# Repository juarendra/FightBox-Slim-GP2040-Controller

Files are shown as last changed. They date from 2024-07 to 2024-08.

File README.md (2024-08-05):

# FightBox-Slim-GP2040-Controller
## Table of Content

* [Product Specsification](#product-specsification)
* [Technical Spesification](#technical-spesification)
* [Priview Hardware](#priview-hardware)
* [Documentation](#documentation)
  * [Pinout Diagram](#pinout-diagram)
  * [Dimension](#dimension)
  * [BOM](#bom)
  * [Schematic](#schematic0)
  * [Example Program](#examples-program)
* [FAQ](#FAQ)

## Priview Hardware
<p align="center">
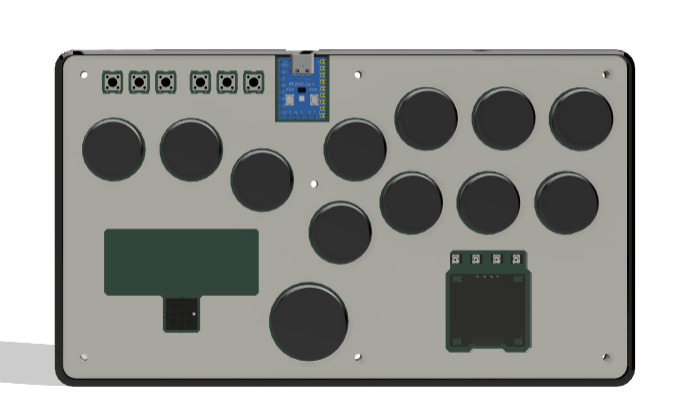
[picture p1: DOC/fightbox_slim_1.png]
  
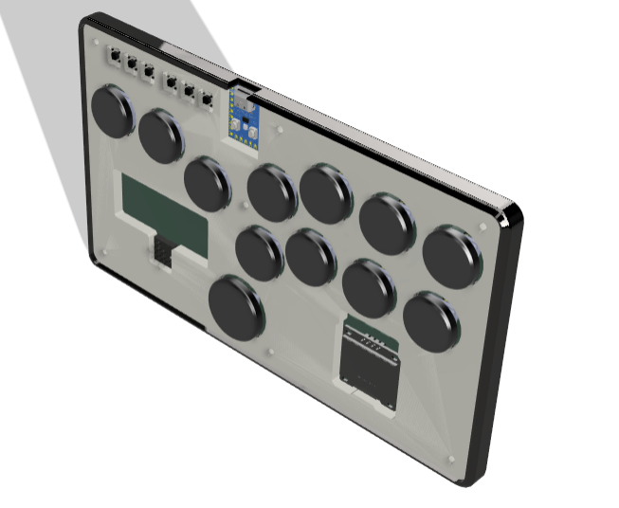
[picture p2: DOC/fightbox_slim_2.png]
  
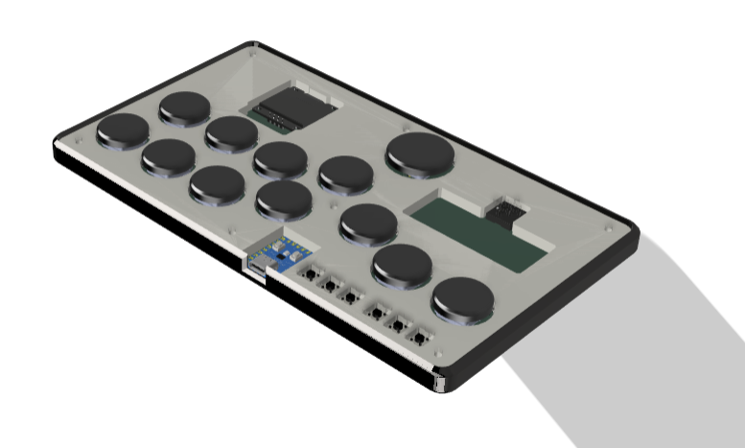
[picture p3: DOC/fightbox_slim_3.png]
  
  
</p>

## Documentation
### Pinout Diagram
<p align="center">
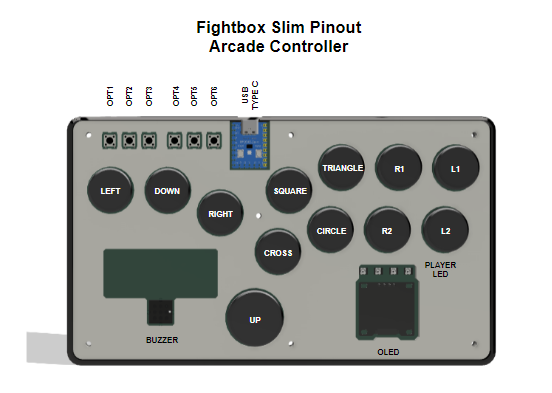
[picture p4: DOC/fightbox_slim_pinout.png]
  
</p>

### Dimension
* [Dimension Board with Component](https://github.com/juarendra/FightBox-Slim-GP2040-Controller/blob/main/HARDWARE/DIMENSION%20ACCES%20FIGHTBOX%20SLIM.pdf)
### BOM
* [BOM Board](https://github.com/juarendra/FightBox-Slim-GP2040-Controller/blob/main/DOC/BOM/FightBox_BOM.xlsx)
### Schematic
* [Schematic](https://github.com/juarendra/FightBox-Slim-GP2040-Controller/blob/main/HARDWARE/fightbox_slim_schematic.pdf)
### Pinout Diagram
* [Pinout Diagram](https://github.com/juarendra/FightBox-Slim-GP2040-Controller/blob/main/HARDWARE/Fightbox_slim_pinout.pdf)

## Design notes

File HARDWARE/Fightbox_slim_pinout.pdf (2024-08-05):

# Fightbox Slim Pinout Arcade Controller

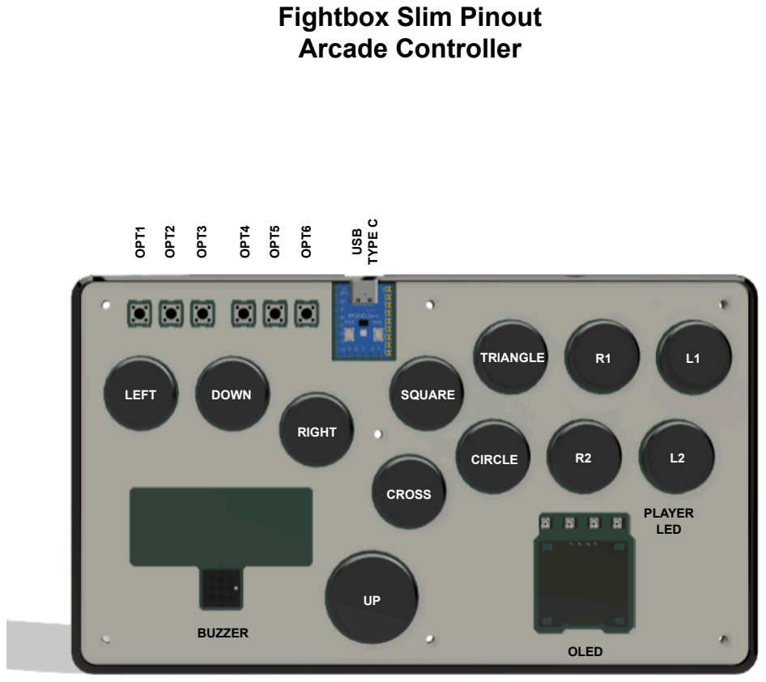
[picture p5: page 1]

LEFT | DOWN

RIGHT

CROSS

SQUARE

CIRCLE

TRIANGLE | R1
R2 | L2

L1

UP

OPT1

OPT2

OPT3

OPT4

OPT5
OPT6
USB

TYPE C

BUZZER
OLED

PLAYER
LED

# Fightbox Slim Pinout Arcade Controller

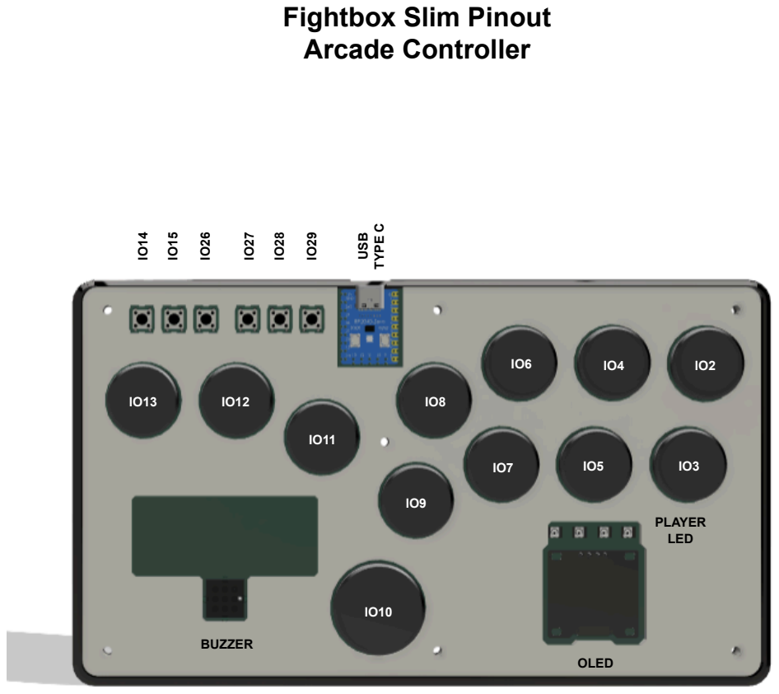
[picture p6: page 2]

IO13 | IO12

IO11

IO9

IO8

IO7

IO6 | IO4
IO5 | IO3 IO2

IO10

IO14

IO15
IO26

IO27

IO28
IO29
USB

TYPE C

BUZZER
OLED

PLAYER
LED

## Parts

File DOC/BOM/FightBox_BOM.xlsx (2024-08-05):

No | Ref | Qnty | Value | Cmp name | Footprint | Description | Tokopedia Link | Note
1 | A1 | 1 | RP2040-Zero | RP2040-Zero | RP2040-Zero:RP2040-Zero |  | https://www.tokopedia.com/hobielektronika/raspberry-pi-pico-rp2040-zero-mikrocontroller-dual-core-cortex-m0 | -
2 | Brd1 | 1 | SSD1306 | SSD1306 | oled:128x64OLED | SSD1306 OLED | https://tokopedia.link/G6XMfRS3NLb | -
3 | BZ1 | 1 | Buzzer | Buzzer | Buzzer_Beeper:Buzzer_Murata_PKLCS1212E | Buzzer, polarized | https://tokopedia.link/6FK5Z8Z3NLb | -
7 | L1, L2, L3, L4, L5, L6, L7, L8, L9, L10, L11, L12, L13, L14, L15, L16, L17, L18, L19, L20, L21, L22, L23, L24, L25, L26, L27, L28 | 28 | kbd_SK6812MINI | kbd_SK6812MINI | kbd:SK6812MINI_rev |  | https://tokopedia.link/y0GYifh4NLb | -
8 | SW1, SW2, SW3, SW4, SW5, SW6 | 6 | SW_Push | SW_Push | Button_Switch_THT:SW_PUSH_6mm_H5mm | Push button switch, generic, two pins | https://tokopedia.link/rqC0fJt4NLb | -
9 | SW7, SW8, SW9, SW10, SW11, SW12, SW13, SW14, SW15, SW16, SW17, SW18 | 12 | SW_Push | SW_Push | keyswitch:Kailh_socket_PG1350 | Push button switch, generic, two pins | https://tokopedia.link/b9QdQEr4NLb | -
10 | SW19, SW20, SW21, SW22, SW23, SW24, SW25, SW26, SW27, SW28, SW29, SW30 | 12 | SW_PUSH | SW_PUSH | keyswitch:Kailh_socket_MX |  | https://tokopedia.link/jJEvHtk4NLb | -

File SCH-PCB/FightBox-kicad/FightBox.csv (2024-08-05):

Source: | C:\Users\jrjua\Documents\Pribadi\Github\FightBox-Slim-GP2040-Controller\SCH-PCB\FightBox-kicad\FightBox.kicad_sch
Date: | 5/8/2024 11:39:31 am
Tool: | Eeschema 7.0.1
Generator: | C:\Program Files\KiCad\7.0\bin\scripting\plugins/bom_csv_grouped_by_value_with_fp.py
Component Count: | 78
Ref | Qnty | Value | Cmp name | Footprint | Description | Vendor | DNP
A1 | 1 | RP2040-Zero | RP2040-Zero | RP2040-Zero:RP2040-Zero
Brd1 | 1 | SSD1306 | SSD1306 | oled:128x64OLED | SSD1306 OLED
BZ1 | 1 | Buzzer | Buzzer | Buzzer_Beeper:Buzzer_Murata_PKLCS1212E | Buzzer, polarized
H1, H2, H3, H4, H5, H6, H7 | 7 | MountingHole | MountingHole | MountingHole:MountingHole_6.4mm_M6 | Mounting Hole without connection
J1, J2, J3, J4, J5 | 5 | i2c_pin-Lily58-cache | i2c_pin-Lily58-cache | solfe:1pin_conn
JP1, JP2, JP3 | 3 | Jumper_3_Open | Jumper_3_Open | Jumper:SolderJumper-3_P1.3mm_Open_RoundedPad1.0x1.5mm | Jumper, 3-pole, both open
JP4, JP5 | 2 | Jumper_2_Open | Jumper_2_Open | Jumper:SolderJumper-2_P1.3mm_Open_RoundedPad1.0x1.5mm | Jumper, 2-pole, open
L1, L2, L3, L4, L5, L6, L7, L8, L9, L10, L11, L12, L13, L14, L15, L16, L17, L18, L19, L20, L21, L22, L23, L24, L25, L26, L27, L28 | 28 | kbd_SK6812MINI | kbd_SK6812MINI | kbd:SK6812MINI_rev
SW1, SW2, SW3, SW4, SW5, SW6 | 6 | SW_Push | SW_Push | Button_Switch_THT:SW_PUSH_6mm_H5mm | Push button switch, generic, two pins
SW7, SW8, SW9, SW10, SW11, SW12, SW13, SW14, SW15, SW16, SW17, SW18 | 12 | SW_Push | SW_Push | keyswitch:Kailh_socket_PG1350 | Push button switch, generic, two pins
SW19, SW20, SW21, SW22, SW23, SW24, SW25, SW26, SW27, SW28, SW29, SW30 | 12 | SW_PUSH | SW_PUSH | keyswitch:Kailh_socket_MX

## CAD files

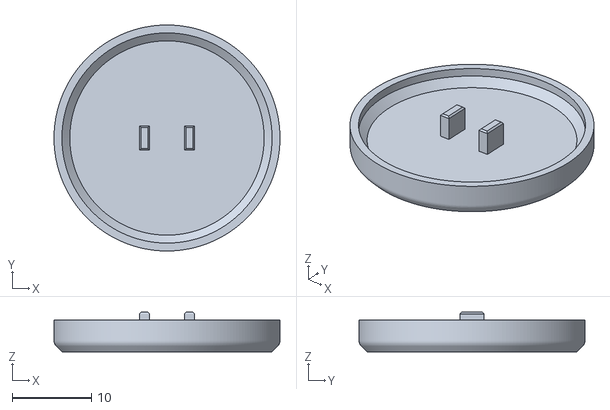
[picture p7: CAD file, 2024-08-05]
HARDWARE/3d Case/ButtoncapBig.stl
28.5 x 28.5 x 5.00

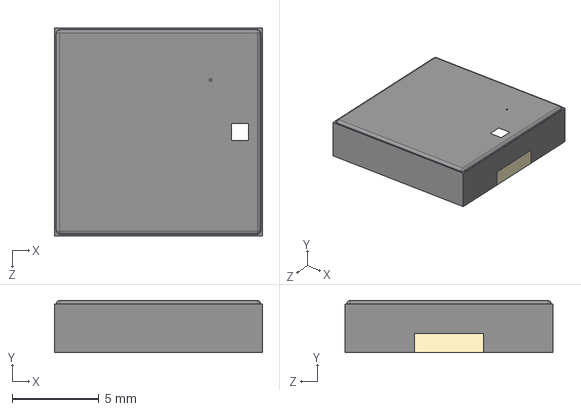
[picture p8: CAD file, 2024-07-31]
SCH-PCB/FightBox-kicad/3d/PKLCS1212E2400-R1.stp
12.0 x 3.00 x 12.0 mm

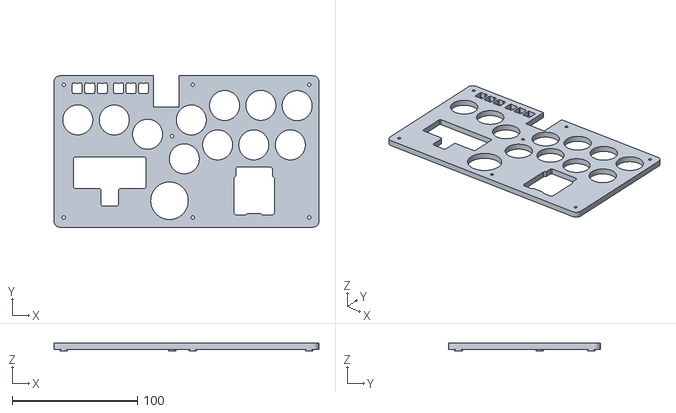
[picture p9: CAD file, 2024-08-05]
HARDWARE/3d Case/fightingbox_slim_MIDDLE_CASE.stl
211.6 x 121.0 x 6.20

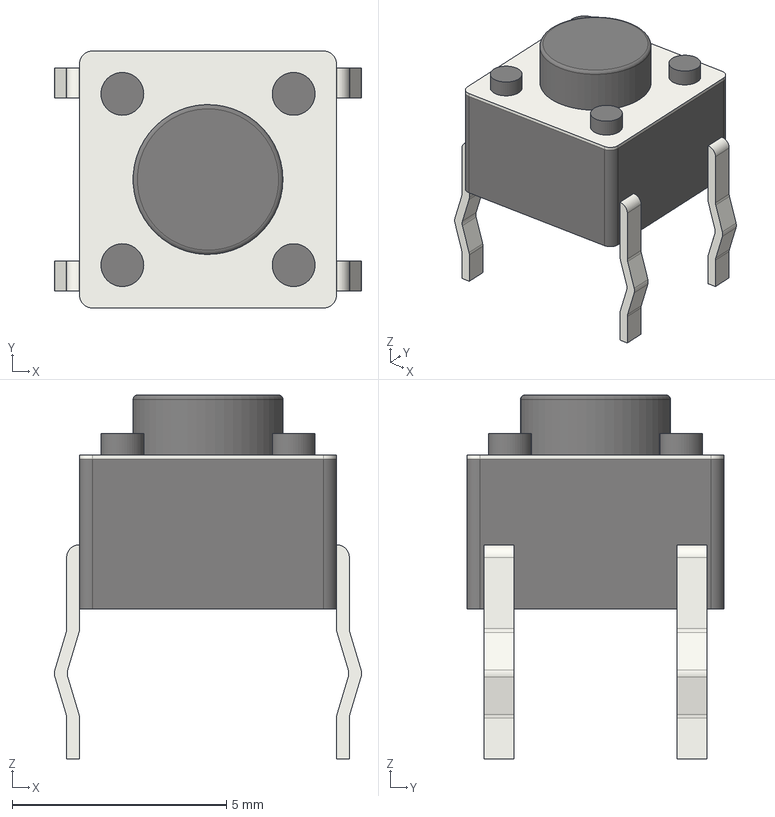
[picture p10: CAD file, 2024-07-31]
SCH-PCB/FightBox-kicad/3d/SW_PUSH_6mm_H5mm.step
7.17 x 6.00 x 8.50 mm

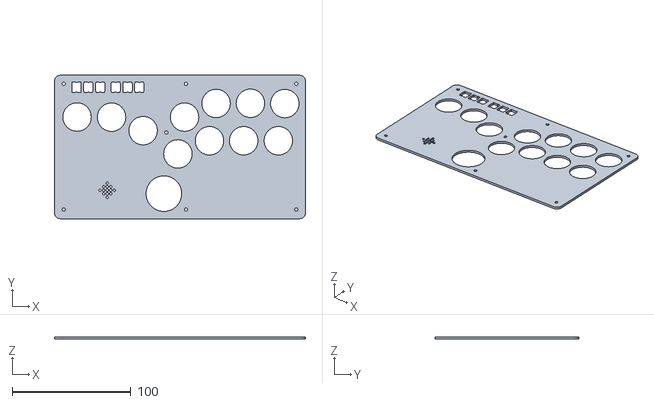
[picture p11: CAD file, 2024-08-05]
HARDWARE/3d Case/fightingbox_slim_TOP_CASE.stl
211.6 x 121.0 x 2.00

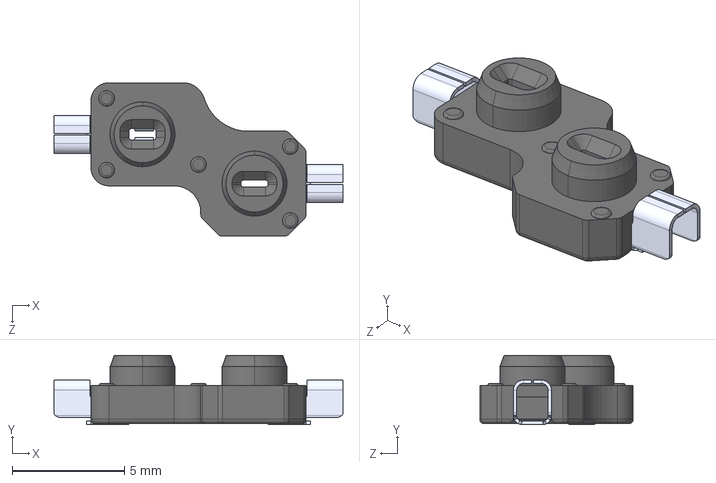
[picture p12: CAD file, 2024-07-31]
SCH-PCB/FightBox-kicad/3d/PG1350-socket.STEP
12.9 x 3.09 x 6.85 mm
pin x 2
socket

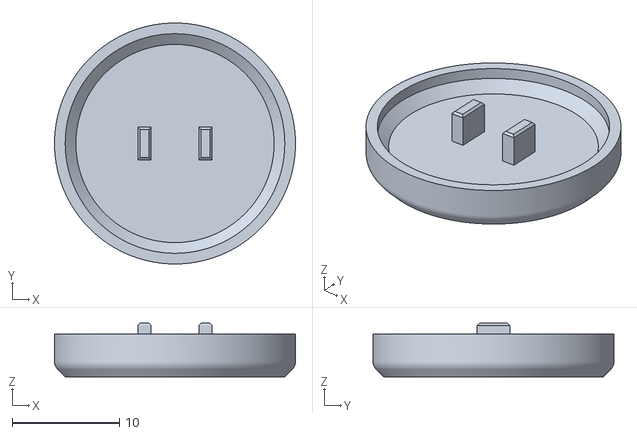
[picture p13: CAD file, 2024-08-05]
HARDWARE/3d Case/Buttoncap.stl
22.5 x 22.5 x 5.00

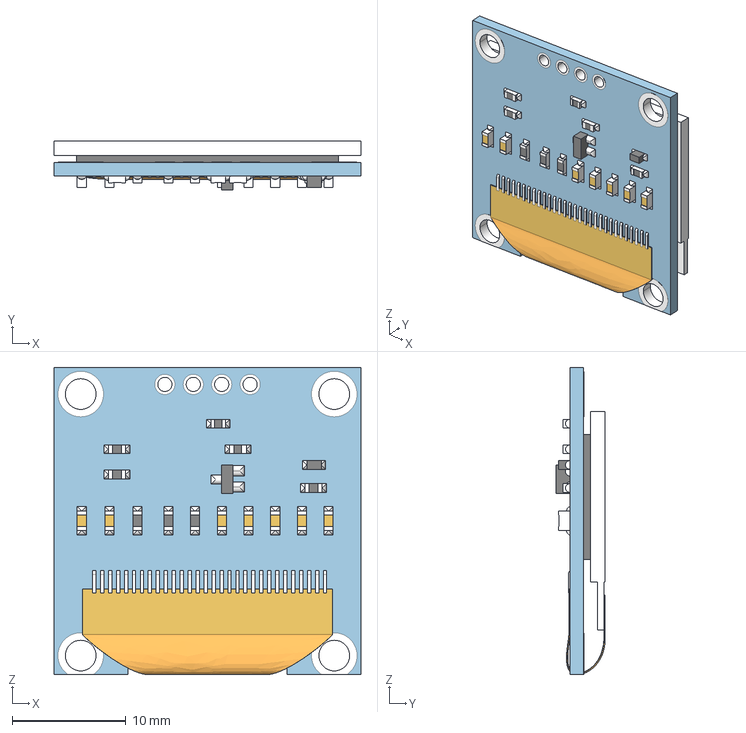
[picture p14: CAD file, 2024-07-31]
SCH-PCB/FightBox-kicad/3d/oled_096_gm009605.stp
27.0 x 4.35 x 27.0 mm

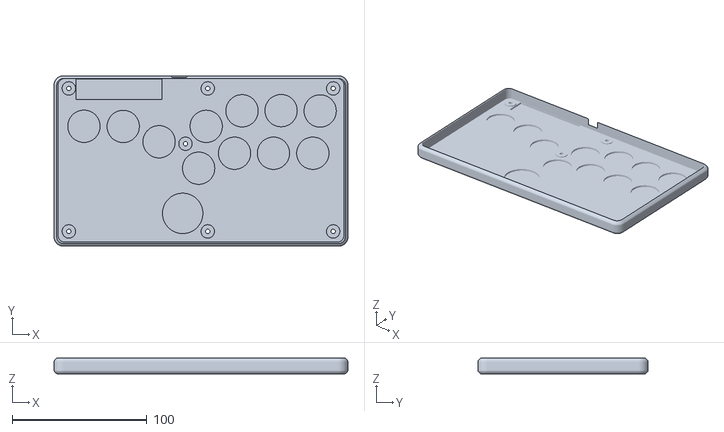
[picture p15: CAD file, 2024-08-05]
HARDWARE/3d Case/fightingbox_slim_BOTTOM_CASE.stl
218.0 x 126.4 x 11.8

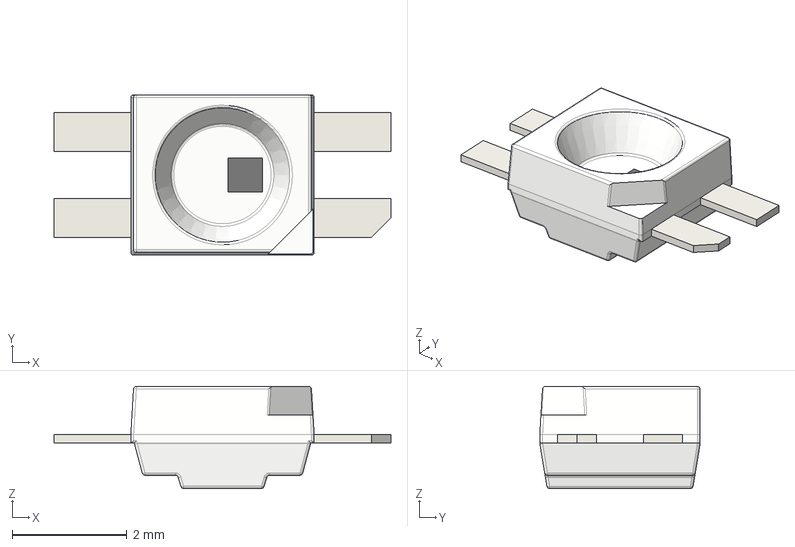
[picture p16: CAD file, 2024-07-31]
SCH-PCB/FightBox-kicad/3d/LED_SK6812MINI-E.step
5.88 x 2.80 x 1.78 mm

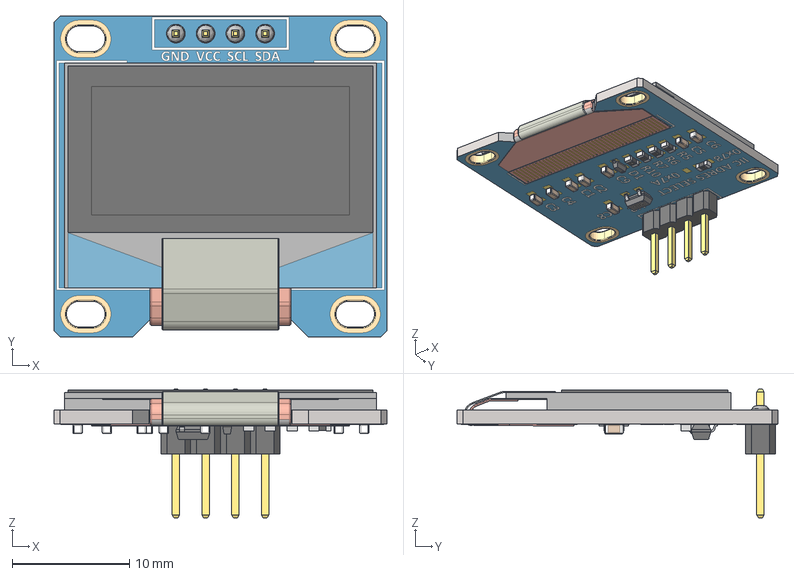
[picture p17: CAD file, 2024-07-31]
SCH-PCB/FightBox-kicad/3d/Pantalla OLED 0.96'' 128x64.stp
28.4 x 27.4 x 11.0 mm
SOT-23_TOR
RES_CR16_MTK_1 x 4
RES_CR16_MTK
SOD323F_DIO

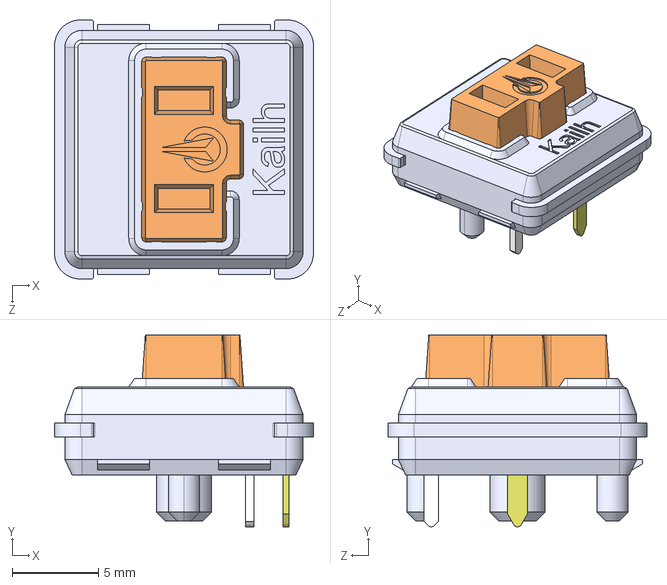
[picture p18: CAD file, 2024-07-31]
SCH-PCB/FightBox-kicad/3d/Kailh LP Choc Burnt Orange.IGS
15.0 x 11.1 x 15.0 mm

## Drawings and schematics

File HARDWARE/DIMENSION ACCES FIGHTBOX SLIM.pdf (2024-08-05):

121 | Ø2.8 ⁹.74 11.47 | Ø3.5

11.8

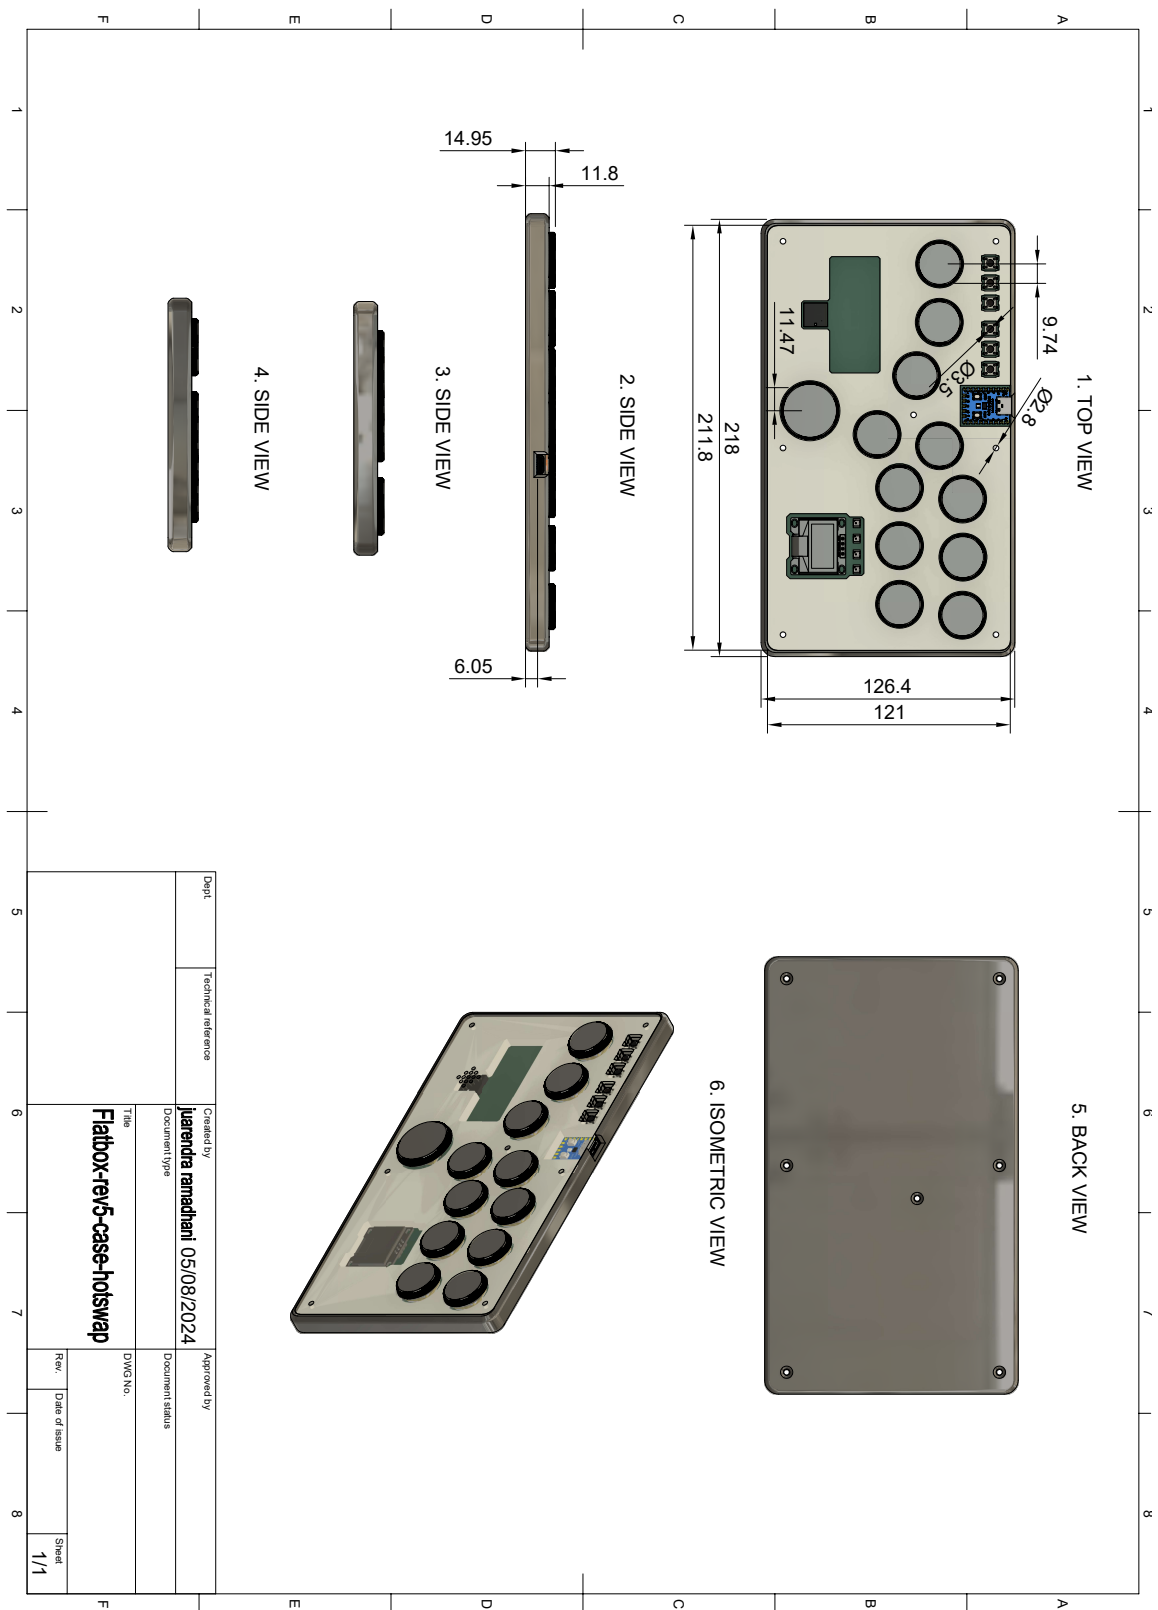
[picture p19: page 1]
126.4 ²¹⁸ ²¹¹.8; 6.05 ⁴. SIDE VIEW; 3. SIDE VIEW; 2. SIDE VIEW; 1. TOP VIEW 6. ISOMETRIC VIEW; 5. BACK VIEW

1 A 2 3 4 5 6 7 8 1 2 3 4 5 6 7 8 FEDCB FEDCBA Dept. Technical reference Created by Approved by Title DWG No. Document type Document status Rev. Date of issue Sheet 05/08/2024 1/1

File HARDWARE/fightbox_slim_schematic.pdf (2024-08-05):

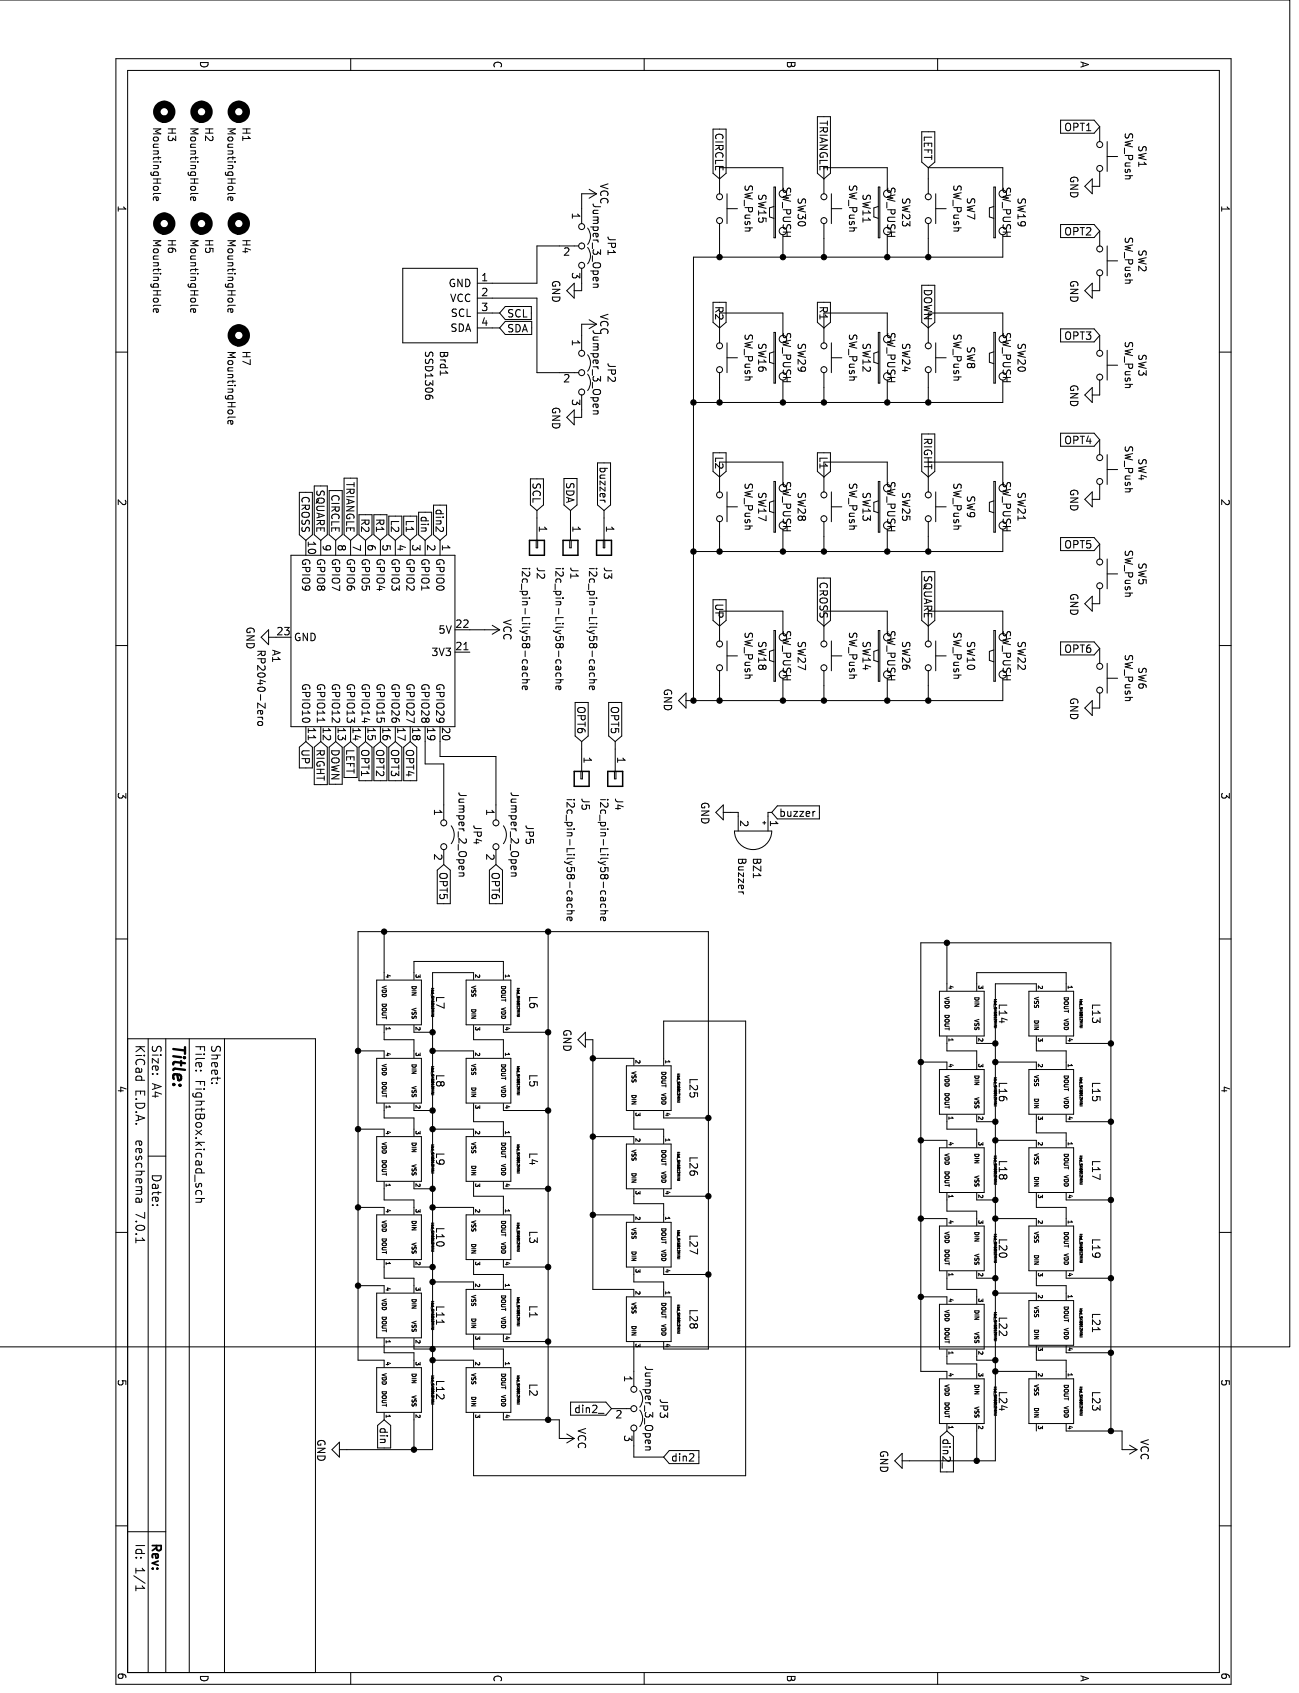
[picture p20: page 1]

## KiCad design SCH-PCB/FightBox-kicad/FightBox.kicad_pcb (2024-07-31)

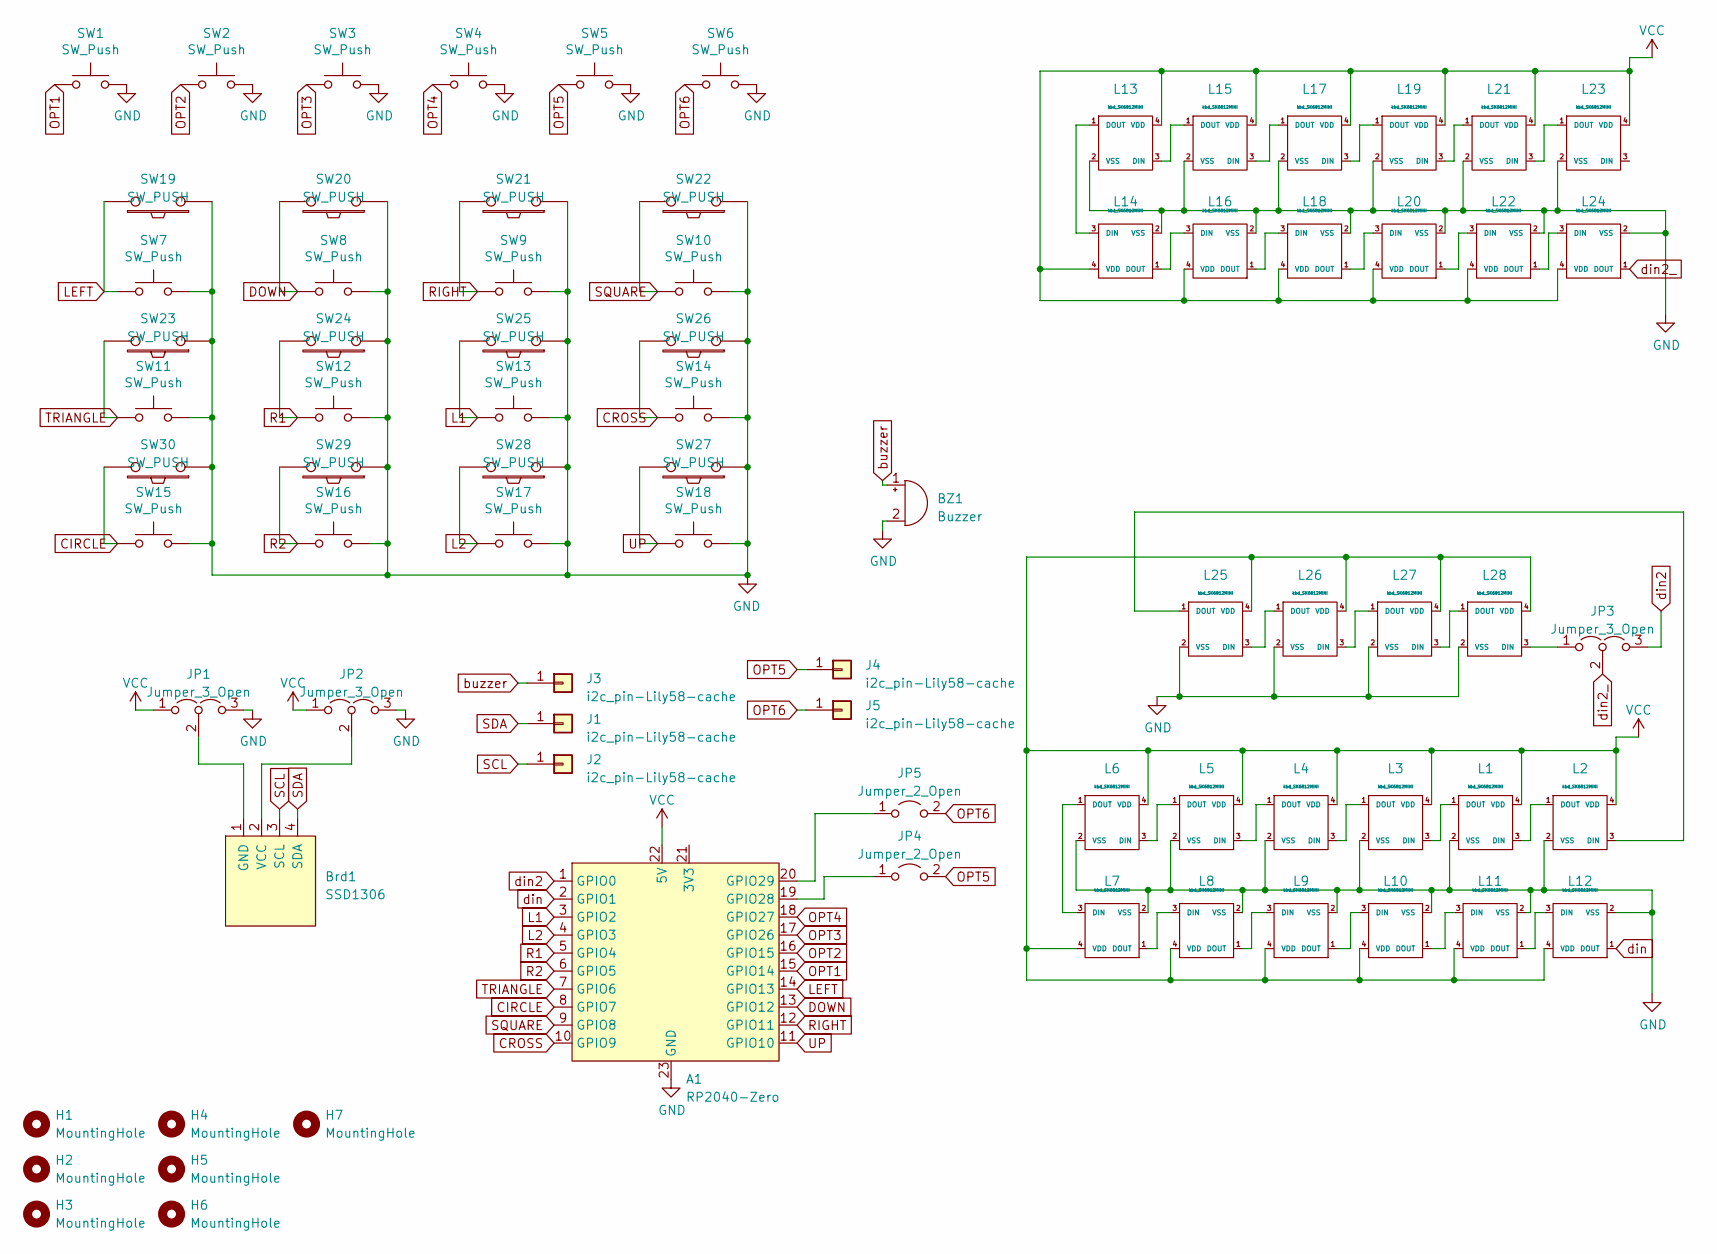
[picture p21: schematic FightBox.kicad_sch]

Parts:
A1: RP2040-Zero
BZ1: Buzzer; Buzzer_Murata_PKLCS1212E
Brd1: SSD1306; 128x64OLED
H1, H2, H3, H4, H5, H6, H7: MountingHole; MountingHole_6.4mm_M6
J1, J2, J3, J4, J5: i2c_pin-Lily58-cache; 1pin_conn
JP1, JP2, JP3: Jumper_3_Open; SolderJumper-3_P1.3mm_Open_RoundedPad1.0x1.5mm
JP4, JP5: Jumper_2_Open; SolderJumper-2_P1.3mm_Open_RoundedPad1.0x1.5mm
L1, L2, L3, L4, L5, L6, L7, L8, L9, L10, L11, L12, L13, L14, L15, L16, L17, L18, L19, L20, L21, L22, L23, L24, L25, L26, L27, L28: kbd_SK6812MINI; SK6812MINI_rev
SW1, SW2, SW3, SW4, SW5, SW6: SW_Push; SW_PUSH_6mm_H5mm
SW7, SW8, SW9, SW10, SW11, SW12, SW13, SW14, SW15, SW16, SW17, SW18: SW_Push; Kailh_socket_PG1350
SW19, SW20, SW21, SW22, SW23, SW24, SW25, SW26, SW27, SW28, SW29, SW30: SW_PUSH; Kailh_socket_MX

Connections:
CIRCLE: A1.8 (GPIO7), SW15.1, SW30.2
CROSS: A1.10 (GPIO9), SW14.1, SW26.2
DOWN: A1.13 (GPIO12), SW8.1, SW20.2
GND: A1.23 (GND), BZ1.2 (+), JP1.3 (B), JP2.3 (B), L1.2 (VSS), L2.2 (VSS), L3.2 (VSS), L4.2 (VSS), L5.2 (VSS), L6.2 (VSS), L7.2 (VSS), L8.2 (VSS), L9.2 (VSS), L10.2 (VSS), L11.2 (VSS), L12.2 (VSS), L13.2 (VSS), L14.2 (VSS), L15.2 (VSS), L16.2 (VSS), L17.2 (VSS), L18.2 (VSS), L19.2 (VSS), L20.2 (VSS), L21.2 (VSS), L22.2 (VSS), L23.2 (VSS), L24.2 (VSS), L25.2 (VSS), L26.2 (VSS), L27.2 (VSS), L28.2 (VSS), SW1.2, SW2.2, SW3.2, SW4.2, SW5.2, SW6.2, SW7.2, SW8.2, SW9.2, SW10.2, SW11.2, SW12.2, SW13.2, SW14.2, SW15.2, SW16.2, SW17.2, SW18.2, SW19.1, SW20.1, SW21.1, SW22.1, SW23.1, SW24.1, SW25.1, SW26.1, SW27.1, SW28.1, SW29.1, SW30.1
L1: A1.3 (GPIO2), SW13.1, SW25.2
L2: A1.4 (GPIO3), SW17.1, SW28.2
LEFT: A1.14 (GPIO13), SW7.1, SW19.2
unnamed: A1.19 (GPIO28), JP4.1 (A)
unnamed: A1.20 (GPIO29), JP5.1 (A)
unnamed: Brd1.1 (GND), JP1.2 (C)
unnamed: Brd1.2 (VCC), JP2.2 (C)
unnamed: JP3.1 (A), L28.3 (DIN)
unnamed: L1.3 (DIN), L2.1 (DOUT)
unnamed: L1.1 (DOUT), L3.3 (DIN)
unnamed: L2.3 (DIN), L25.1 (DOUT)
unnamed: L3.1 (DOUT), L4.3 (DIN)
unnamed: L4.1 (DOUT), L5.3 (DIN)
unnamed: L5.1 (DOUT), L6.3 (DIN)
unnamed: L6.1 (DOUT), L7.3 (DIN)
unnamed: L7.1 (DOUT), L8.3 (DIN)
unnamed: L8.1 (DOUT), L9.3 (DIN)
unnamed: L9.1 (DOUT), L10.3 (DIN)
unnamed: L10.1 (DOUT), L11.3 (DIN)
unnamed: L11.1 (DOUT), L12.3 (DIN)
unnamed: L13.3 (DIN), L15.1 (DOUT)
unnamed: L13.1 (DOUT), L14.3 (DIN)
unnamed: L14.1 (DOUT), L16.3 (DIN)
unnamed: L15.3 (DIN), L17.1 (DOUT)
unnamed: L16.1 (DOUT), L18.3 (DIN)
unnamed: L17.3 (DIN), L19.1 (DOUT)
unnamed: L18.1 (DOUT), L20.3 (DIN)
unnamed: L19.3 (DIN), L21.1 (DOUT)
unnamed: L20.1 (DOUT), L22.3 (DIN)
unnamed: L21.3 (DIN), L23.1 (DOUT)
unnamed: L22.1 (DOUT), L24.3 (DIN)
unnamed: L25.3 (DIN), L26.1 (DOUT)
unnamed: L26.3 (DIN), L27.1 (DOUT)
unnamed: L27.3 (DIN), L28.1 (DOUT)
OPT1: A1.15 (GPIO14), SW1.1
OPT2: A1.16 (GPIO15), SW2.1
OPT3: A1.17 (GPIO26), SW3.1
OPT4: A1.18 (GPIO27), SW4.1
OPT5: J4.1, JP4.2 (B), SW5.1
OPT6: J5.1, JP5.2 (B), SW6.1
R1: A1.5 (GPIO4), SW12.1, SW24.2
R2: A1.6 (GPIO5), SW16.1, SW29.2
RIGHT: A1.12 (GPIO11), SW9.1, SW21.2
SCL: Brd1.3 (SCL), J2.1
SDA: Brd1.4 (SDA), J1.1
SQUARE: A1.9 (GPIO8), SW10.1, SW22.2
TRIANGLE: A1.7 (GPIO6), SW11.1, SW23.2
UP: A1.11 (GPIO10), SW18.1, SW27.2
VCC: A1.22 (5V), JP1.1 (A), JP2.1 (A), L1.4 (VDD), L2.4 (VDD), L3.4 (VDD), L4.4 (VDD), L5.4 (VDD), L6.4 (VDD), L7.4 (VDD), L8.4 (VDD), L9.4 (VDD), L10.4 (VDD), L11.4 (VDD), L12.4 (VDD), L13.4 (VDD), L14.4 (VDD), L15.4 (VDD), L16.4 (VDD), L17.4 (VDD), L18.4 (VDD), L19.4 (VDD), L20.4 (VDD), L21.4 (VDD), L22.4 (VDD), L23.4 (VDD), L24.4 (VDD), L25.4 (VDD), L26.4 (VDD), L27.4 (VDD), L28.4 (VDD)
buzzer: BZ1.1 (-), J3.1
din: A1.2 (GPIO1), L12.1 (DOUT)
din2: A1.1 (GPIO0), JP3.3 (B)
din2_: JP3.2 (C), L24.1 (DOUT)

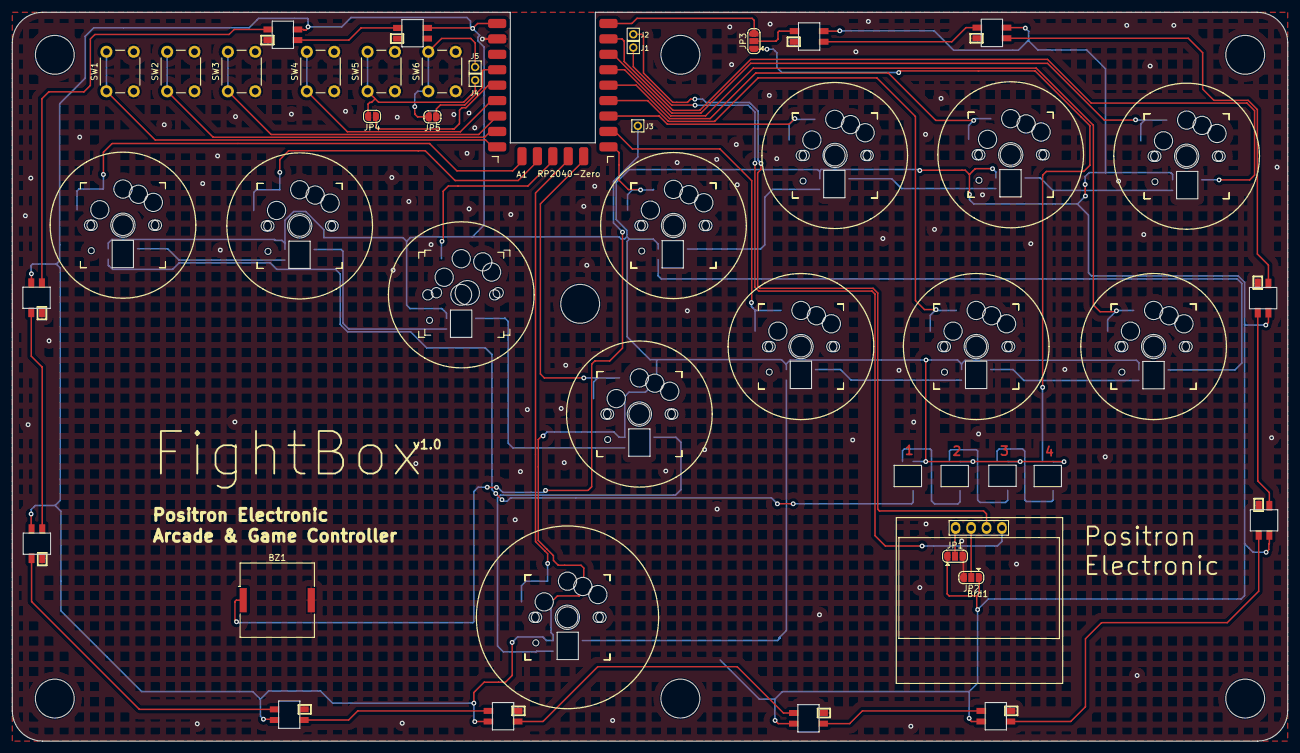
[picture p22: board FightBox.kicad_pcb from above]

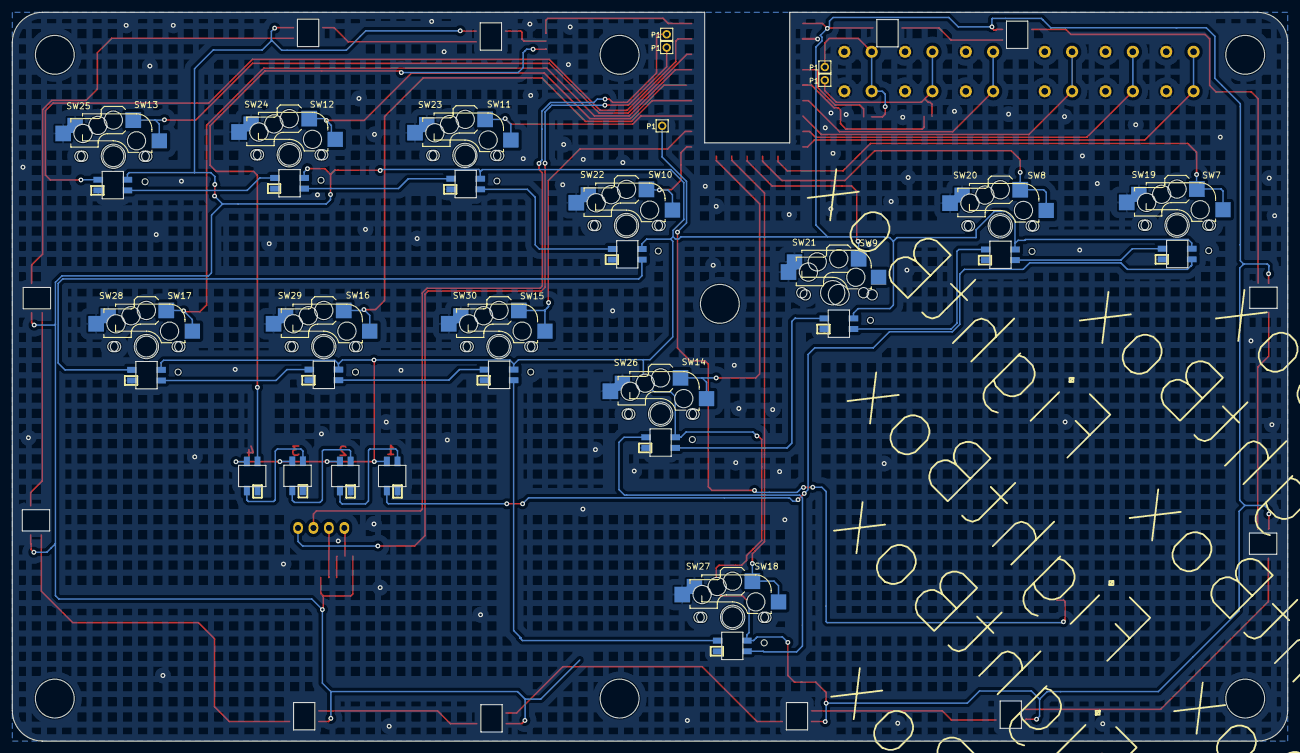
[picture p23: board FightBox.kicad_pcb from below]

Board: 2 copper layers, 210.0 x 120.0 mm, 78 parts (12 on the bottom side), 57 nets.

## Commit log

2024-08-05 FEAT: add 3d model, case, shematic
    [Buttoncap.stl, ButtoncapBig.stl, fightingbox_slim_BOTTOM_CASE.stl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]
2024-08-05 FEATL: add BOM List
    [FightBox.csv, FightBox_BOM.xlsx]
